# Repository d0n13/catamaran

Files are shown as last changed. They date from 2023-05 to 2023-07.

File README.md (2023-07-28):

# Electric catamaran

Boat with two catamaran hulls with trusters driven by a joystick. Two ESC controllers driving the trusters and everything running on a rasspberry pi pico in micropython. Battery pack is a 5s12p pack driving the trusters. 1.2kw output. 21700 batteries

Hardware designed in [Fusion 360](https://gmail362014.autodesk360.com/g/projects/20220607531689401/data/dXJuOmFkc2sud2lwcHJvZDpmcy5mb2xkZXI6Y28uRkVOcG5FTk5Rc0s0LTh4UGM5VVRHdw)

799f17a9-d0db-46f9-a08c-765364c65fe4
bc107527-6c7e-486d-8713-1d385c604de5
IMG_7667_Original

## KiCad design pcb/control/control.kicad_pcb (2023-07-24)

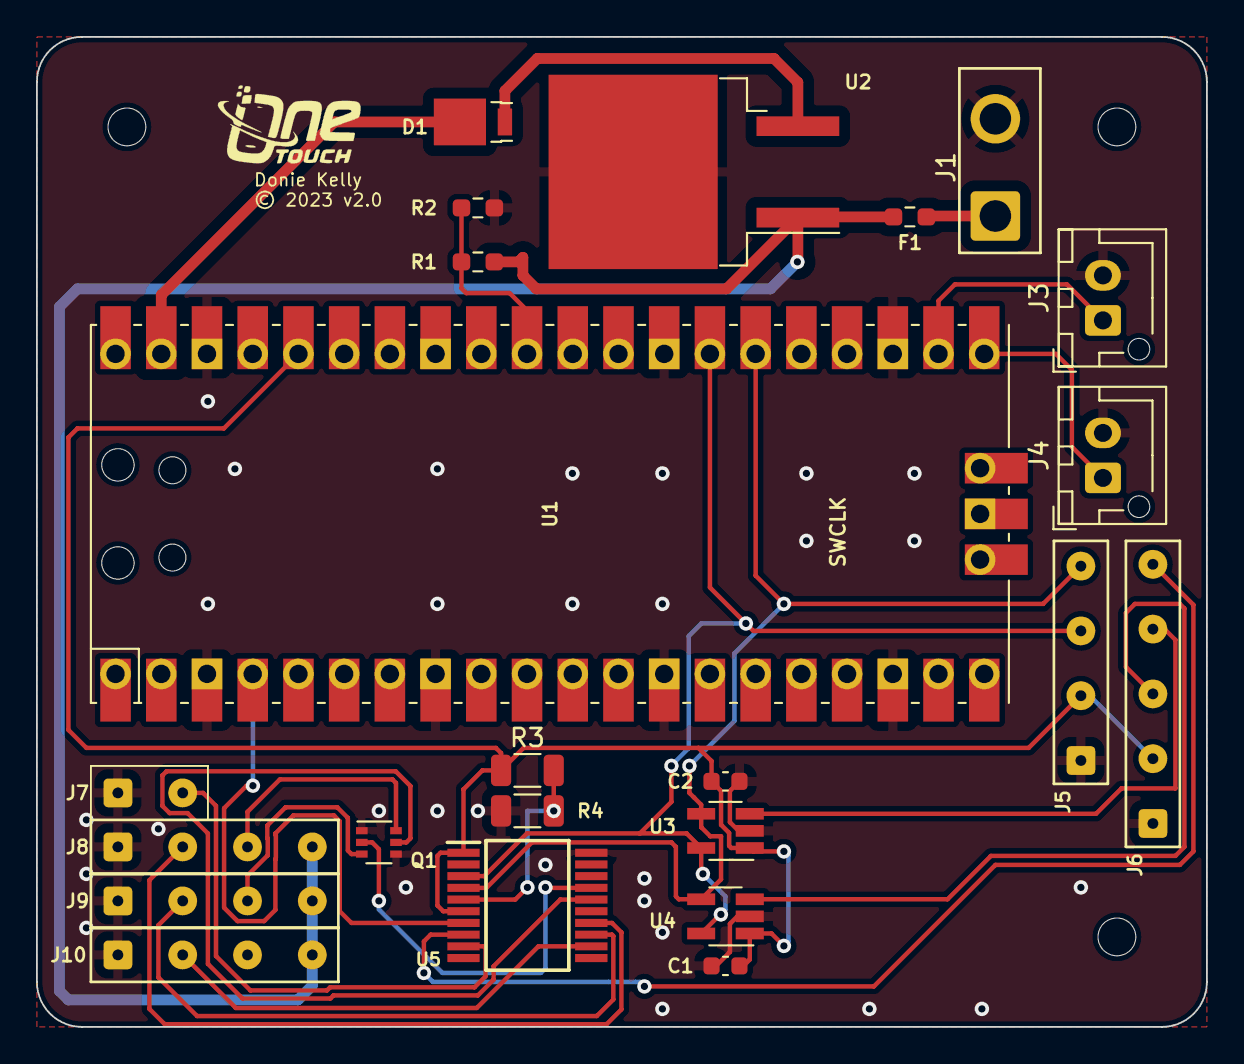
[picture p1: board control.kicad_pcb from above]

Board: 2 copper layers, 65.0 x 55.0 mm, 27 parts (0 on the bottom side), 24 nets.

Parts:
C1, C2: 0.1µF; C_0603_1608Metric
D1: D_Schottky; DO220AA
F1: SMD Fuse; R_0603_1608Metric_Pad0.98x0.95mm_HandSolder
G1: LOGO; onetouchlogo
H1, H2, H3: MountingHole; MountingHole_2.1mm
J1: 24v; SolderWire-1sqmm_1x02_P5.4mm_D1.4mm_OD2.7mm
J3: ESC 1 PCM; JST_XH_B2B-XH-AM_1x02_P2.50mm_Vertical
J4: ESC 2 PCM; JST_XH_B2B-XH-AM_1x02_P2.50mm_Vertical
J5: OLED; SolderWire-0.1sqmm_1x04_P3.6mm_D0.4mm_OD1mm
J6: Joystick; SolderWire-0.1sqmm_1x05_P3.6mm_D0.4mm_OD1mm
J7: Cutout; SolderWire-0.1sqmm_1x02_P3.6mm_D0.4mm_OD1mm
J8: Switch 1; SolderWire-0.1sqmm_1x04_P3.6mm_D0.4mm_OD1mm
J9: Switch 2; SolderWire-0.1sqmm_1x04_P3.6mm_D0.4mm_OD1mm
J10: Switch 3; SolderWire-0.1sqmm_1x04_P3.6mm_D0.4mm_OD1mm
Q1: US6K1; SOT-363_SC-70-6
R1: 100k; R_0603_1608Metric_Pad0.98x0.95mm_HandSolder
R2: 18K; R_0603_1608Metric_Pad0.98x0.95mm_HandSolder
R3: 1K; R_1206_3216Metric
R4: 15K; R_1206_3216Metric
U1: Pico; RPi_Pico_SMD_TH
U2: L7805; TO-263-2
U3, U4: MCP3021; SOT-23-5_HandSoldering
U5: MCP23009-E_SS; SOP65P780X200-20N

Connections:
+3V3: C1.1, C2.1, J5.2, J6.2, R3.1, U1.36 (3V3), U3.1 (VCC), U4.1 (VCC), U5.1 (VDD), U5.6 (~RESET)
+24V: F1.2, J8.4, J9.4, J10.4, R1.1, U2.1 (IN)
+BATT: F1.1, J1.1
GND: C1.2, C2.2, J1.2, J3.2, J4.2, J5.1, J6.1, J7.1, J8.1, J9.1, J10.1, Q1.1 (S), Q1.4 (S), R2.2, R4.2, U1.3 (GND), U1.8 (GND), U1.13 (GND), U1.18 (GND), U1.23 (GND), U1.28 (GND), U1.38 (GND), U2.2 (GND), U3.2 (GND), U4.2 (GND), U5.20 (VSS)
unnamed: D1.1 (K), U1.39 (VSYS)
unnamed: D1.2 (A), U2.3 (OUT)
unnamed: J3.1, U1.22 (GPIO17)
unnamed: J4.1, U1.21 (GPIO16)
unnamed: J6.3, U3.3 (AIN)
unnamed: J6.4, U4.3 (AIN)
unnamed: J6.5, U5.8 (GP0)
unnamed: J7.2, U5.9 (GP1)
unnamed: J8.2, U5.14 (GP4)
unnamed: J8.3, Q1.6 (D)
unnamed: J9.2, U5.13 (GP3)
unnamed: J9.3, Q1.3 (D)
unnamed: J10.2, U5.12 (GP2)
unnamed: Q1.2 (G), U5.17 (GP7)
unnamed: Q1.5 (G), U5.16 (GP6)
unnamed: R1.2, R2.1, U1.31 (GPIO26_ADC0)
unnamed: R3.2, R4.1, U5.5 (ADDR)
unnamed: U1.4 (GPIO2), U5.7 (INT)
SCL: J5.3, U1.27 (GPIO21), U3.5 (SCL), U4.5 (SCL), U5.3 (SCL)
SDA: J5.4, U1.26 (GPIO20), U3.4 (SDA), U4.4 (SDA), U5.4 (SDA)

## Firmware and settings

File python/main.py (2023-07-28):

from time import sleep
import oleddisplay as oleddisplay
import joystick
import mcp23009 as Controls
import truster
import thread_i2c
import _thread

# init
i2c = thread_i2c.ThreadSafeI2C()
display = oleddisplay.OLED(i2c=i2c)
joystick = joystick.Joystick(i2c=i2c)

# Init MCP23009 to control buttons and lights
controls = Controls.mcp23009(i2c=i2c)
controls.setupIO()
t200 = truster.PowerManager(display)

def timeCrit():
    print("Starting...")
    while True:
        axis = joystick.readAxis()
        pcm = joystick.steering(axis)
        if not controls.isSafetyOn():
            t200.killTrusters()
        else:
            t200.setTrusterPCM(pcm)

        if controls.isJoystickHatOn():
            print("HAT")
        sleep(0.1)

def displayUpdates():
    while True:
        controls.readGPIO()
        display.updateBattery()

        buttons = controls.readButtons()
        display.showButtons(buttons)
        button1, button2, button3 = buttons

        display.setCruise(button2)
        display.showSafety(controls.isSafetyOn())

        display.showTrusterPower()
        display.updateDisplay()

        sleep(0.05)

# Run display on one thread and main control loop on other
if __name__ == "__main__":
    _thread.start_new_thread(displayUpdates, ())
    timeCrit()

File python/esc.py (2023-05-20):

import time 
from time import sleep
from machine import ADC, Pin, PWM, ADC, I2C
import ssd1306
import oleddisplay
import util

# init display
display = oleddisplay.OLED()
display.updateBattery(75)

util.flashLED()

# Use pin #0 and # 1 for ESC controller 1 and 2
trusterRight = PWM(Pin(0)); trusterRight.freq(50)
trusterLeft = PWM(Pin(1)); trusterLeft.freq(50)

# Joystick x axis
joyX = ADC(27)
# Joystick y axis
joyY = ADC(26)

speedProfile = 0
speedProfileLastTime = time.time()
masterArm = 0
masterArmTime = time.time()
lastSteerPosition = 50

def speedProfileCallback(swValue):
    global speedProfile
    global speedProfileLastTime

    pressTime = time.time()
    if pressTime - 2  > speedProfileLastTime:  
        if joySw.value() == 0:
            if speedProfile == 0:
                print("High power")
                speedProfile = 1
            else:
                print("Low power")
                speedProfile = 0
        speedProfileLastTime = time.time()
    # else:
    #     print("ignored")

# Joystick input switch
joySw = Pin(28, Pin.IN, Pin.PULL_UP)
joySw.irq(trigger=Pin.IRQ_FALLING, handler=speedProfileCallback)

# map function
def map(x, in_min, in_max, out_min, out_max):
    return int((x - in_min) * (out_max - out_min) / (in_max - in_min) + out_min)

# Set speeds to be same on both ESC controllers
# Map the value from 0-100% to a pulse from 1100ms to 1900ms for high speed
# Map the value from 0-100% to a pulse from 1400ms to 1600ms for low speed
def speed(speed):
    if speedProfile == 1:
        speed = map(speed, 0,100, 1100,1900) #ESC
    else:
        speed = map(speed, 0,100, 1400,1600) #ESC

    trusterRight.duty_ns(speed * 1000) # in nanoseconds
    trusterLeft.duty_ns(speed * 1000) # in nanoseconds
    # print(speed)
        
# Turn off the outputs
def escOff():
    trusterRight.duty_ns(0)
    trusterLeft.duty_ns(0)

# Arm the ESC controllers, not sure if this is correct yet as it depends on the state of the controller
# and I need to test this under the conditions that it's in effect
def arm():
    print("Arming")
    speed(0)
    sleep(2)
    print("Ready")

# Steering
def joystickToTrottle():
    y = joyY.read_u16()                 # Read the joystick
    # print("y: " + str(y))
    mappedY = map(y, 0,65535, 0,100)    # Map to a range 0-100. Center position is 50
    speed(mappedY)

def checkIfArmed():
    global masterArmTime
    global masterArm

    arm = joySw.value()
    if not arm:
        pressTime = time.time()
        # print("pressTime: " + str(pressTime))
        # print("masterTime: " + str(masterArmTime))

        if pressTime - 2  > masterArmTime:
            
            masterArmTime = pressTime
            masterArm = not masterArm
            print("Arming: " + str(masterArm)) # need to latch the value between on and off as sw is momentary
    
    
    
# Main Loop
while True:
    joystickToTrottle()
    sleep(0.1)

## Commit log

2022-06-12 Map joystick axis to servos and motors. Clean up code
2022-06-13 Added master arm and steering mod
2022-07-05 Created PCB design
    [control.kicad_pcb, control.kicad_sch]
2022-07-08 Updated pcb
    [control-B_Cu.gbr, control-B_Mask.gbr, control-B_Paste.gbr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]
2022-07-24 v2 of design
    [control.kicad_pcb, control.kicad_sch]
2023-05-20 Updated pcb and code
    [control-B_Cu.gbr, control-B_Mask.gbr, control-B_Paste.gbr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]
2023-05-23 Version 2.0 sent to manafacture
    [control-B_Cu.gbr, control-B_Mask.gbr, control-B_Paste.gbr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]
2023-07-18 Updated code
    [control.kicad_sch]
2023-07-24 library code update
    [control.kicad_pcb, control.kicad_sch]
2023-07-28 Fixed joystick mapping code
    [joystick.py]
2023-07-28 Add files via upload
    boat render (right hull)
2023-07-28 Update README.md
    Added image of pcb

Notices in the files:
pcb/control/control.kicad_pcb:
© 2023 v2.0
